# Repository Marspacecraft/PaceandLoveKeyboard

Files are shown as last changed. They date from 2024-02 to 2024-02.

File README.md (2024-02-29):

# PaceandLoveKeyboard
    受稚晖君启发，当时的铝厂的F96正好罢工，于是准备自己做一款键盘。
    改装的铝厂F96键盘
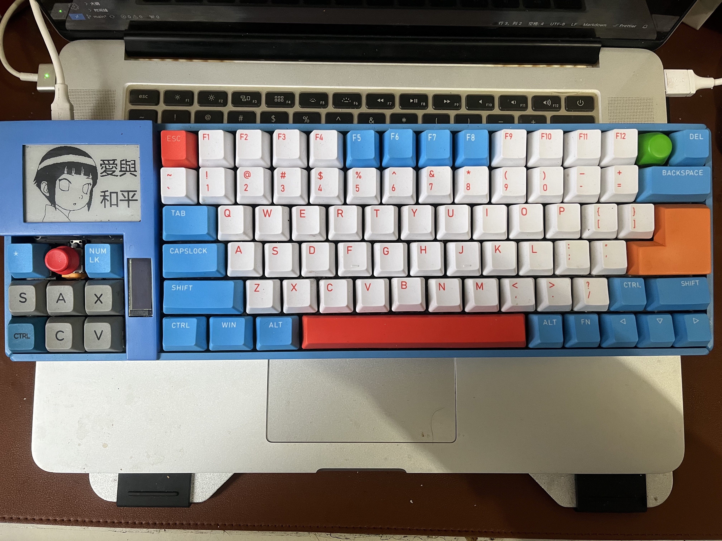
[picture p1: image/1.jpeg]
    
    当时正好缅北内战，于是起名爱与和平键盘。
## 目录
    3D-freecad做的一些3D模型
    Frameware-键盘固件
        bootloader-引导固件
        PaceandLoveKeyboard-键盘固件
            CherryUSB-usbd代理，主要实现usb的hid和mcp的串口设别
            core-键盘主要代码
                Epaper，Oled，Fonts-调试的一些显示模块驱动
                Flash-外部flash，无法作为MSC设别，暂未调试成功
                joystick-摇杆驱动
                Keyboard-键盘相关代码
                Src-系统启动等相关代码
            Fatfs-文件系统。主要用于stm32内部flash和外部flash
            OBJ-键盘固件生成目录
            SFUD-外部flash驱动
            Ymodem-串口Ymodem协议，用于串口传输文件
    Hardware-嘉立创做的硬件电路（Flash处可能存在问题，无法做将外部flash做成MSC，问题目前没有解决，flash暂时没有使用）---本人纯属自学电路制作，电路图仅供参考。
    BLE-低功耗蓝牙，采用的是nrf52832，融合了nrf的两个demo，数据可以正常发送，但问题太多，以后有时间解决。

## 键盘原理
    keybit-物理按键编号
    keycode-hid报告的键盘键值
    keycombine-按键组合。一个keycombine对应一个keybit；keycombine由4个keycode组成。一个keycombine相当于同时按下数个键。
    hid报告描述
        8bit功能按键位
        8bit填充位
        6*8bit所有按键位
        104bit普通按键位
        5bit LED显示位
        3bit填充位

        共22byte，目前LED功能没有实现。

    按键扫描采用稚晖君的方案，定时通过移位寄存器读取按键状态，将按键状态保存到sg_BitMap_New中。经过抖动延时后再次读区按键状态到sg_BitMap_Debound。通过对比将结果保存到sg_BitMap_Old中。当按键按下时通过keybit对应的keycombine找到对应的keycode进行发送。

    按键映射层通过修改keycombine映射的keycode实现不同层以及修改键值等的管理。

## 灯效
    见[rgbmode.h](https://github.com/Marspacecraft/PaceandLoveKeyboard/blob/main/Frameware/PaceAndLoveKeyboard/Core/Led/rgbmode.h)文件说明

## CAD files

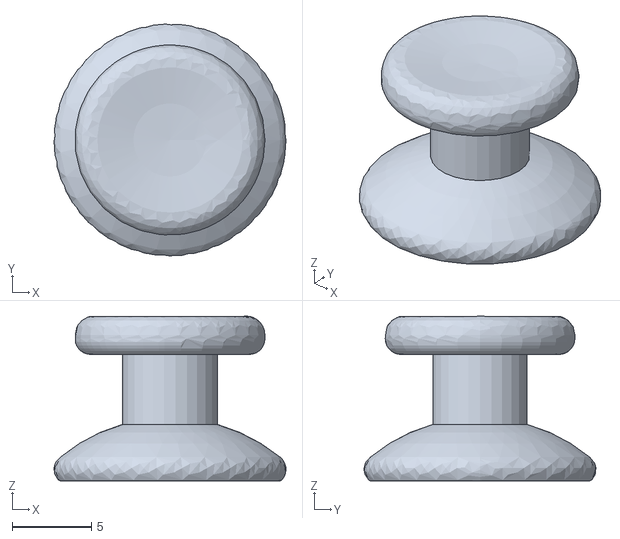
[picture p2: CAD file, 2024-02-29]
3D/Keyboard-摇杆.stl
14.7 x 14.6 x 10.4

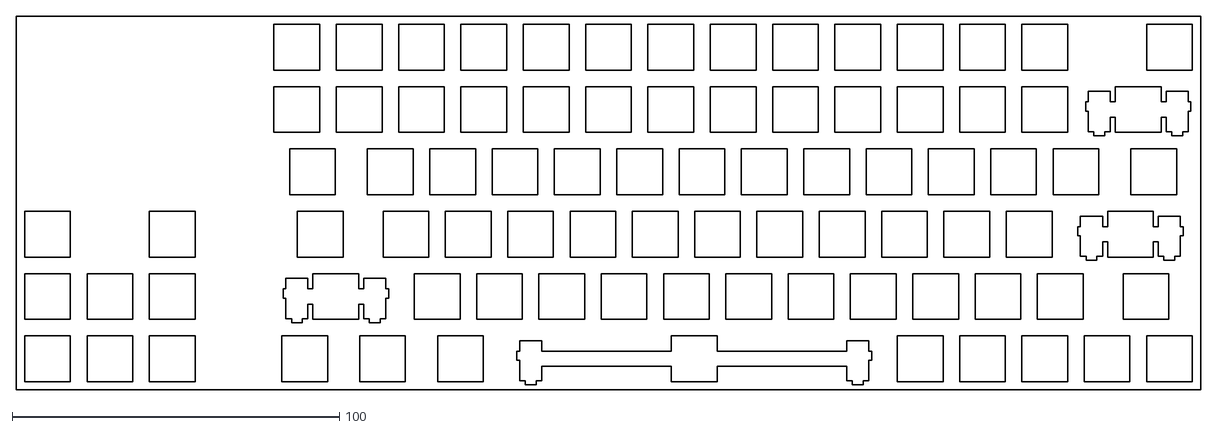
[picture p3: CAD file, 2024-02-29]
Hardware/定位板.dxf
361.9 x 114.3

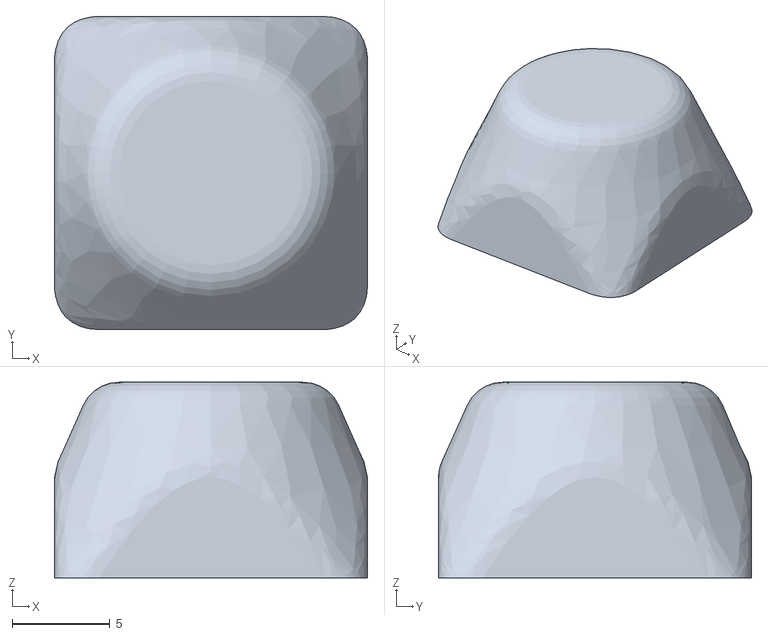
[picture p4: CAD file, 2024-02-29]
3D/Keyboard-电源键.stl
16.0 x 16.0 x 10.0

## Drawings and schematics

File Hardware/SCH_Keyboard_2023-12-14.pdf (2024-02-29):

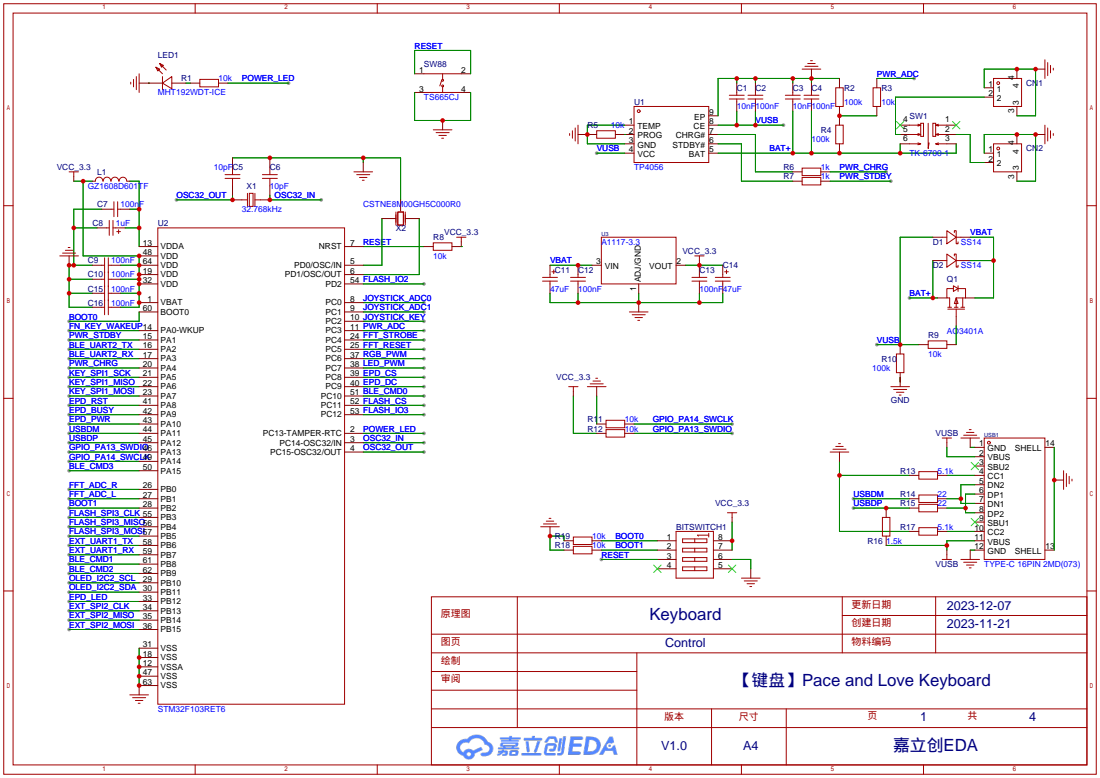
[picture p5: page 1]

【键盘】Pace and Love Keyboard

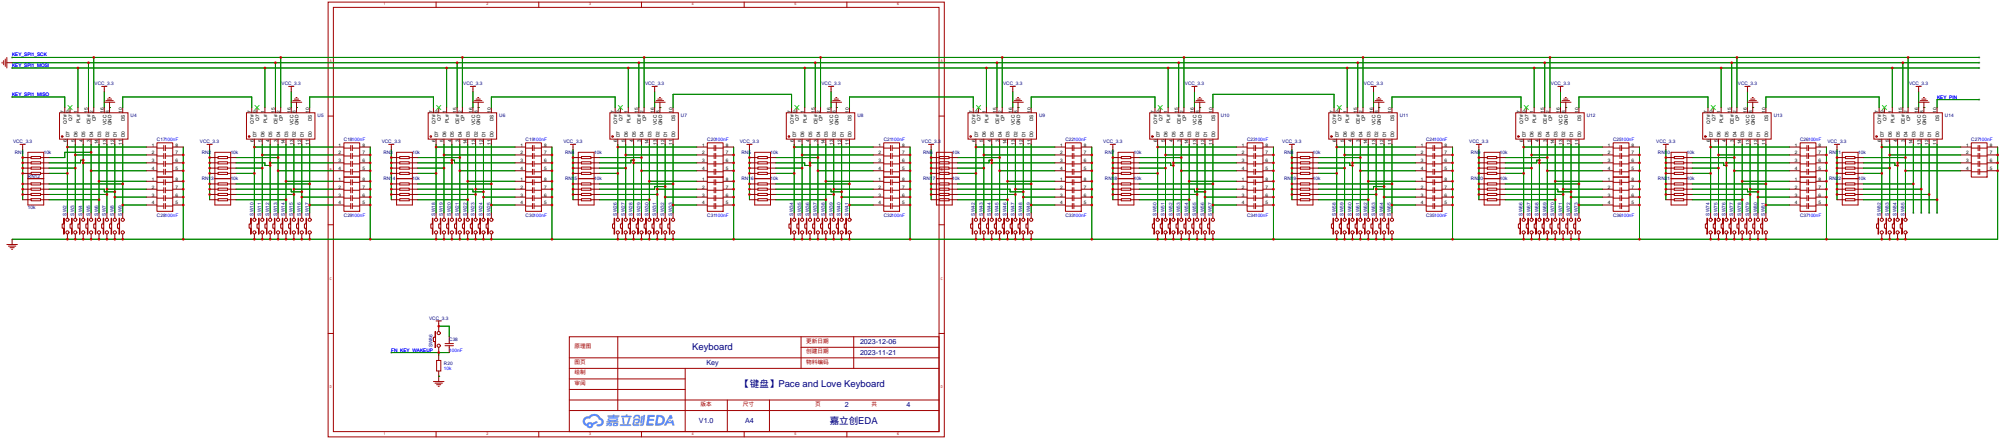
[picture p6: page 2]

KEY_SPI1_MOSI

VCC_3.3 | VCC_3.3 | VCC_3.3 | VCC_3.3 | VCC_3.3 | VCC_3.3 | VCC_3.3 | VCC_3.3 | VCC_3.3 | VCC_3.3

2023-11-21 Keyboard
Key
【键盘】Pace and Love Keyboard

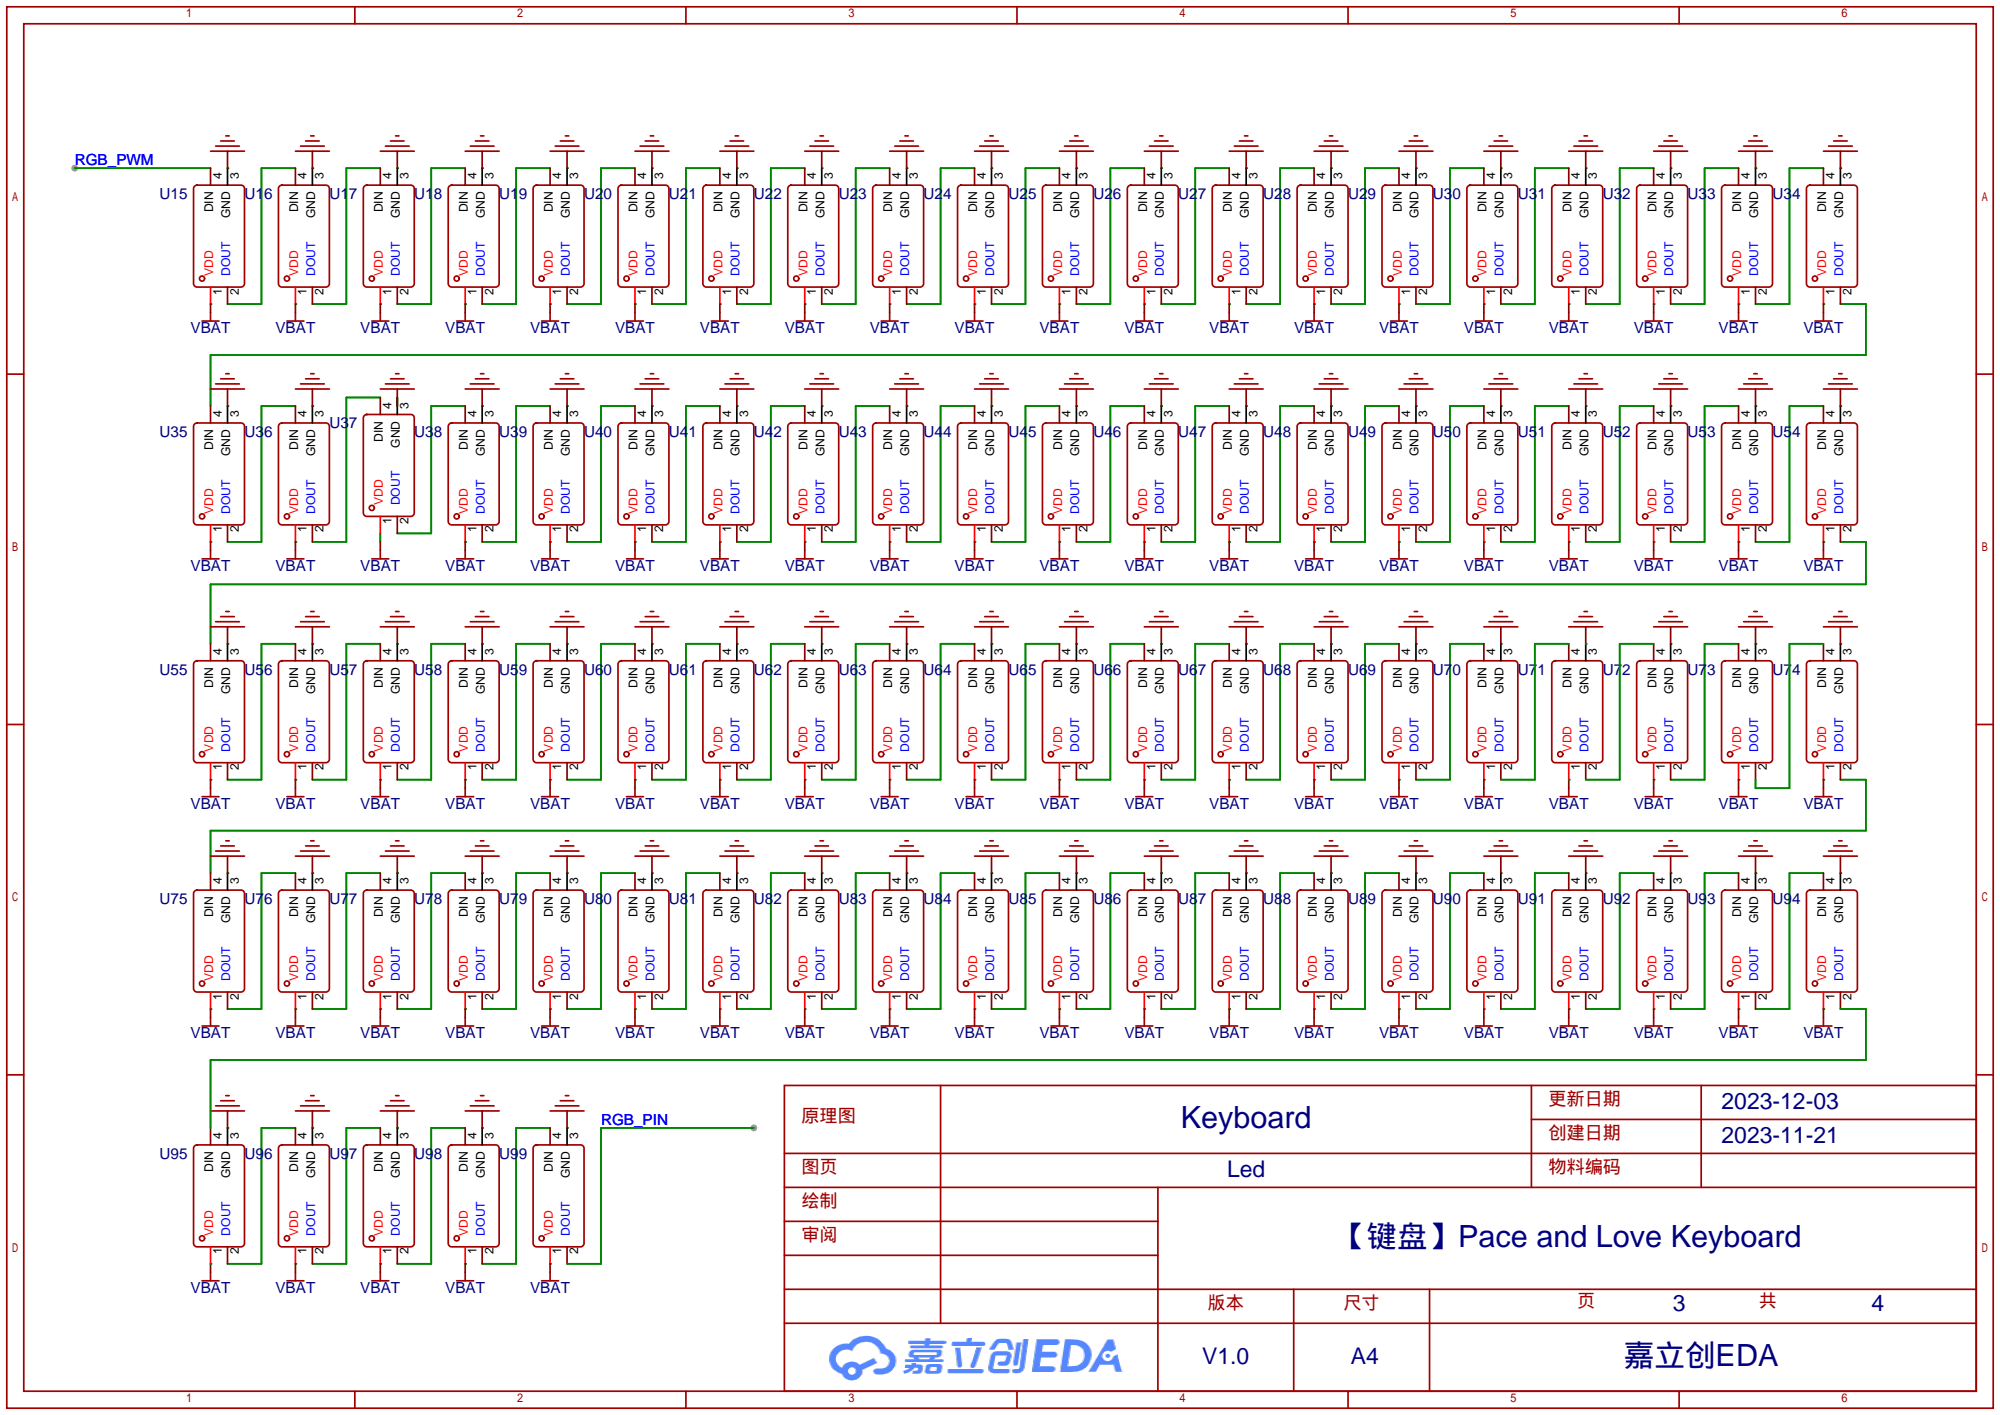
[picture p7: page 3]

2023-11-21 Keyboard
Led
【键盘】Pace and Love Keyboard

# THB001P JOYSTICK_KEY

P0.24 42 P0.23 41 P0.22 40 SWDIO 39 SWDCLK 38 P0.21 37 P0.20 36 P0.19 35 P0.18 34 P0.17 33 P0.16 32 P0.15 31 P0.14 30 P0.13 29

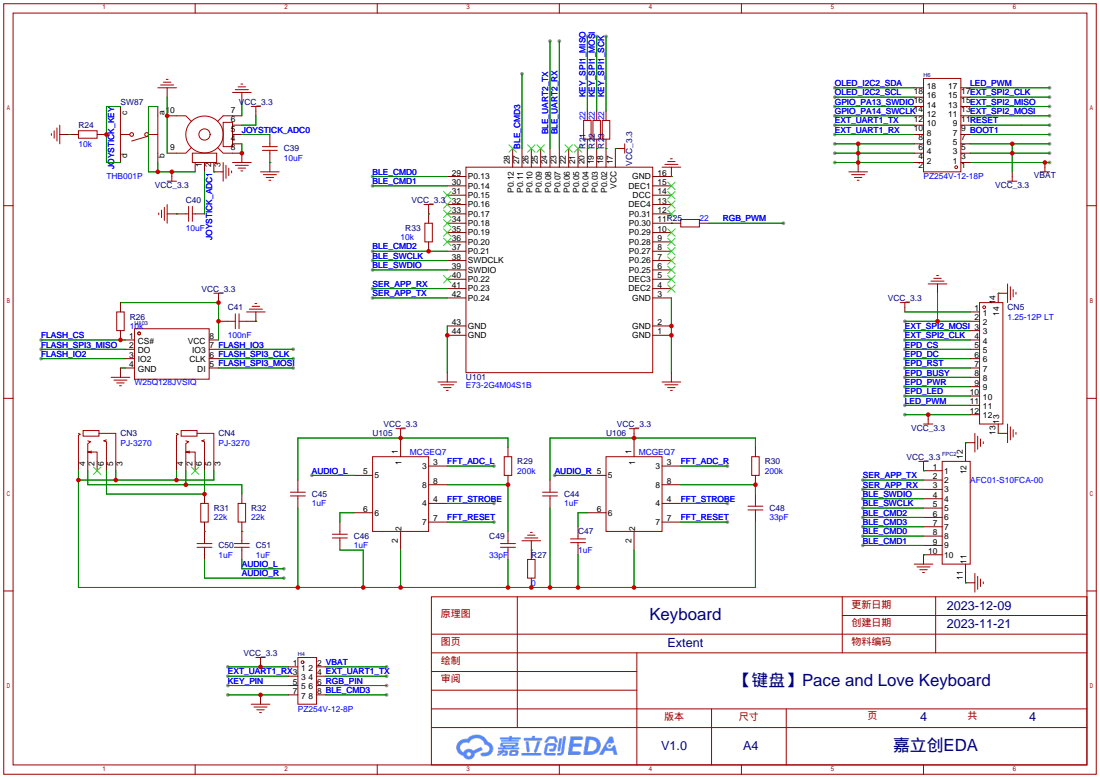
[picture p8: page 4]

2023-11-21 Keyboard
Extent
【键盘】Pace and Love Keyboard

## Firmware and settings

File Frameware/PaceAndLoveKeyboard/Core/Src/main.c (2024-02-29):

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
/* Includes ------------------------------------------------------------------*/
#include "main.h"
#include "adc.h"
#include "dma.h"
#include "i2c.h"
#include "spi.h"
#include "tim.h"
#include "usart.h"
#include "usb_device.h"
#include "gpio.h"

/* USER CODE BEGIN Includes */
#include "keyconfig.h"
#include "tracelog.h"
#include "usbd_agent.h"
#include "scheduler.h"
#include "keyboard.h"
#include "memery.h"
#include "flash.h"
#include "fatfs.h"
#include "EPD_2in7_V2.h"
#include "timertask.h"
#include "timeradc.h"
#include "joystick.h"
#include "fonts.h"
#include "st7302.h"
#include "rgb.h"
#include "ws2812b.h"
#include "oled.h"
/* USER CODE END Includes */


void SystemClock_Config(void);
/* USER CODE BEGIN 0 */


void KB_Delay_us(uint32_t us)
{
	uint32_t i = us * 18;//nop,i--,judge,jump 72/4=18

	for(;i>0;i--)
	{
		__NOP();
	}
}

bool KB_ATOMIC_CAS(volatile uint8_t *pdst,uint8_t osrc,uint8_t nsrc)
{
	bool ret = false;
	
	__disable_irq();
	
	if(*pdst == osrc)
	{
		*pdst = nsrc;
		ret = true;
	}
	__DMB();
	__enable_irq();
	return ret;
}

bool KB_ATOMIC_CAS_ADDR(volatile void **pdst,void * osrc,void * nsrc)
{
	bool ret = false;
	
	__disable_irq();
	
	if(*pdst == osrc)
	{
		*pdst = nsrc;
		ret = true;
	}
	__DMB();
	__enable_irq();
	return ret;
}

void usb_dc_low_level_init(void)
{
    /* Peripheral clock enable */
    __HAL_RCC_USB_CLK_ENABLE();
    /* USB interrupt Init */
    HAL_NVIC_SetPriority(USB_LP_CAN1_RX0_IRQn, 0, 0);
    HAL_NVIC_EnableIRQ(USB_LP_CAN1_RX0_IRQn);

}

void testcase_led_toggle(uint8_t* data)
{
	HAL_GPIO_TogglePin(POWER_LED_GPIO_Port,POWER_LED_Pin);	
}

void Throw_PowerLedTask()
{
	Start_CycleTimer(TIMER_PERIOD_500MS,testcase_led_toggle,NULL);
}

void USB_Init()
{
#ifndef TEST_USB_MSC
	if(MEM_FlagBit_IsEnabled(MEM_FLAG_USBMSC))
	{
		usbd_start_msc_mode();
		MEM_FlagBit_Reset(MEM_FLAG_USBMSC);
		MEM_FlagBit_Set(MEM_FLAG_BOOTLOADER);//enable bootloader to update firmware
	}
	else
	{
		usbd_start_hid_vcp_mode();
	}
#endif

}

void Main()
{
	RGB_CloseAll();
	RGB_Stop();
	CycleTimer_Init();
	Flash_Init();
	Fonts_Init();
	
	USB_Init();
	
	#ifdef SPI_EPAPER
		EPD_StartShow();
	#endif

	#ifdef I2C_OLED
		OLED_Init();
	#ifdef TEST_OLED
		testcase_oled();
	#endif
	#endif
	
	KEY_Init();
	Joystick_Init();

	#ifdef SPI_SHOW_LCD
	LCD_Init();
	#endif
	
	#ifdef USE_TESTCASE
		Throw_PowerLedTask();
	#endif
	
	#ifdef TEST_USB
		HAL_Delay(10000);
		testcase_usb();
	#endif

	#ifdef TEST_74HC165
		extern void testcase_74hc165(void);
 		testcase_74hc165();
	#endif

	#ifdef TEST_SCHEDULER
		testcase_scheduler();
	#endif

	#ifdef TEST_KEYTASKSCHEDULER
		testcase_keytaskscheduler();
	#endif

	#ifdef TEST_RGB
		void testcase_rgb(void);
		testcase_rgb();
	#endif

	#ifdef TEST_INTFLASH
		testcase_intflash();
	#endif
	
	#ifdef TEST_NORFLASH
		testcase_norflash();
	#endif

	#ifdef TEST_FATFS
		extern void testcase_fatfs(void);
		testcase_fatfs();
	#endif

	#ifdef TEST_USB_MSC
		testcase_usbmsc();
	#endif

	#ifdef TEST_EPAPER
		extern void testcase_ePaper(void);
		testcase_ePaper();
	#endif

	#ifdef TEST_TIMERTASK
 		testcase_timertask();
	#endif

	#ifdef TEST_ADC
		testcase_adc();
	#endif

	#ifdef TEST_JOYSTICK
		testcase_joystick();
	#else
		//ADC_Start();
		//Joystick_Start();
	#endif

	#ifdef TEST_FNKEY
		testcase_Fnkey();
	#endif

	#ifdef TEST_LCD
		extern void testcase_lcd(void);
		testcase_lcd();
	#endif

	#ifdef TEST_FONT
		extern void testcase_font(void);
 		testcase_font();
	#endif

	
	#ifdef TEST_REGMODE
		extern void testcase_testrgbmode(void);
		testcase_testrgbmode();	
	#endif

	#ifdef TEST_GT20
		extern void testcase_gt20(void);
		testcase_gt20();
	#endif

	ADC_Start();
	Joystick_Start();
	RGB_Start(RGB_Init_KeyCross);

	extern void ginisobeautiful();
	ginisobeautiful();
	
	HAL_Delay(1000);

	KEY_Scan_Start();
	
	while (1)
  	{
		do_schedule();

  	}
}

void sys_nvic_set_vector_table()
{
    SCB->VTOR = FLASH_BASE | (APP_OFFSET & (uint32_t)0xFFFFFE00);
}

/* USER CODE END 0 */

/**
  * @brief  The application entry point.
  * @retval int
  */
int main(void)
{
  /* USER CODE BEGIN 1 */
	//#ifndef USE_TESTCASE
		sys_nvic_set_vector_table();
	//#endif
	IntFlash_Init();
	init_scheduler();
  /* USER CODE END 1 */

  /* MCU Configuration--------------------------------------------------------*/

  /* Reset of all peripherals, Initializes the Flash interface and the Systick. */
  HAL_Init();

  /* Configure the system clock */
  SystemClock_Config();

  /* Initialize all configured peripherals */
  MX_GPIO_Init();
  MX_DMA_Init();
  MX_USART1_UART_Init();
  MX_SPI1_Init();
  MX_TIM6_Init();
  MX_SPI2_Init();
  MX_SPI3_Init();
  MX_USART2_UART_Init();
  MX_I2C2_Init();
  MX_TIM8_Init();
  MX_ADC1_Init();
  MX_USB_DEVICE_Init();
  /* USER CODE BEGIN 2 */
	TRACELOG_INFO("KeyBoard start!");
  TRACELOG_INFO(PALK_VERSION);
	Main();
  /* USER CODE END 2 */

  /* Infinite loop */
  /* USER CODE BEGIN WHILE */
  while (1)
  {
    /* USER CODE END WHILE */

    /* USER CODE BEGIN 3 */
  }
  /* USER CODE END 3 */
}

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


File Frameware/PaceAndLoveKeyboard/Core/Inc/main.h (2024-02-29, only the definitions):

#define POWER_LED_Pin GPIO_PIN_13
#define POWER_LED_GPIO_Port GPIOC
#define JOYSTICK_ADC0_Pin GPIO_PIN_0
#define JOYSTICK_ADC0_GPIO_Port GPIOC
#define JOYSTICK_ADC1_Pin GPIO_PIN_1
#define JOYSTICK_ADC1_GPIO_Port GPIOC
#define JOYSTICK_KEY_Pin GPIO_PIN_2
#define JOYSTICK_KEY_GPIO_Port GPIOC
#define PWR_ADC_Pin GPIO_PIN_3
#define PWR_ADC_GPIO_Port GPIOC
#define FN_KEY_WAKEUP_Pin GPIO_PIN_0
#define FN_KEY_WAKEUP_GPIO_Port GPIOA
#define FN_KEY_WAKEUP_EXTI_IRQn EXTI0_IRQn
#define PWR_STDBY_Pin GPIO_PIN_1
#define PWR_STDBY_GPIO_Port GPIOA
#define PWR_CHRG_Pin GPIO_PIN_4
#define PWR_CHRG_GPIO_Port GPIOA
#define KEY_SPI1_SCK_Pin GPIO_PIN_5
#define KEY_SPI1_SCK_GPIO_Port GPIOA
#define KEY_SPI1_MISO_Pin GPIO_PIN_6
#define KEY_SPI1_MISO_GPIO_Port GPIOA
#define KEY_PL_Pin GPIO_PIN_7
#define KEY_PL_GPIO_Port GPIOA
#define FFT_STROBE_Pin GPIO_PIN_4
#define FFT_STROBE_GPIO_Port GPIOC
#define FFT_RESET_Pin GPIO_PIN_5
#define FFT_RESET_GPIO_Port GPIOC
#define FFT_ADC_R_Pin GPIO_PIN_0
#define FFT_ADC_R_GPIO_Port GPIOB
#define FFT_ADC_L_Pin GPIO_PIN_1
#define FFT_ADC_L_GPIO_Port GPIOB
#define BOOT1_Pin GPIO_PIN_2
#define BOOT1_GPIO_Port GPIOB
#define OLED_I2C2_SCL_Pin GPIO_PIN_10
#define OLED_I2C2_SCL_GPIO_Port GPIOB
#define OLED_I2C2_SDA_Pin GPIO_PIN_11
#define OLED_I2C2_SDA_GPIO_Port GPIOB
#define EPD_LED_Pin GPIO_PIN_12
#define EPD_LED_GPIO_Port GPIOB
#define EXT_SPI2_CLK_Pin GPIO_PIN_13
#define EXT_SPI2_CLK_GPIO_Port GPIOB
#define EXT_SPI2_MISO_Pin GPIO_PIN_14
#define EXT_SPI2_MISO_GPIO_Port GPIOB
#define EXT_SPI2_MOSI_Pin GPIO_PIN_15
#define EXT_SPI2_MOSI_GPIO_Port GPIOB
#define RGB_PWM_Pin GPIO_PIN_6
#define RGB_PWM_GPIO_Port GPIOC
#define LED_PWM_Pin GPIO_PIN_7
#define LED_PWM_GPIO_Port GPIOC
#define EPD_CS_Pin GPIO_PIN_8
#define EPD_CS_GPIO_Port GPIOC
#define EPD_DC_Pin GPIO_PIN_9
#define EPD_DC_GPIO_Port GPIOC
#define EPD_RST_Pin GPIO_PIN_8
#define EPD_RST_GPIO_Port GPIOA
#define EPD_BUSY_Pin GPIO_PIN_9
#define EPD_BUSY_GPIO_Port GPIOA
#define EPD_PWR_Pin GPIO_PIN_10
#define EPD_PWR_GPIO_Port GPIOA
#define BLE_CMD3_Pin GPIO_PIN_15
#define BLE_CMD3_GPIO_Port GPIOA
#define BLE_CMD0_Pin GPIO_PIN_10
#define BLE_CMD0_GPIO_Port GPIOC
#define FLASH_CS_Pin GPIO_PIN_11
#define FLASH_CS_GPIO_Port GPIOC
#define FLASH_IO3_Pin GPIO_PIN_12
#define FLASH_IO3_GPIO_Port GPIOC
#define FLASH_IO2_Pin GPIO_PIN_2
#define FLASH_IO2_GPIO_Port GPIOD
#define FLASH_SPI3_CLK_Pin GPIO_PIN_3
#define FLASH_SPI3_CLK_GPIO_Port GPIOB
#define FLASH_SPI3_MISO_Pin GPIO_PIN_4
#define FLASH_SPI3_MISO_GPIO_Port GPIOB
#define FLASH_SPI3_MOSI_Pin GPIO_PIN_5
#define FLASH_SPI3_MOSI_GPIO_Port GPIOB
#define EXT_UART1_TX_Pin GPIO_PIN_6
#define EXT_UART1_TX_GPIO_Port GPIOB
#define EXT_UART1_RX_Pin GPIO_PIN_7
#define EXT_UART1_RX_GPIO_Port GPIOB
#define BLE_CMD1_Pin GPIO_PIN_8
#define BLE_CMD1_GPIO_Port GPIOB
#define BLE_CMD2_Pin GPIO_PIN_9
#define BLE_CMD2_GPIO_Port GPIOB

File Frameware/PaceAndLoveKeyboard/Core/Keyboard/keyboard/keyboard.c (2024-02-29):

#include "keyboard.h"
#include "main.h"
#include "usbd_agent.h"
#include <string.h>
#include "gpio.h"
#include "keylayer.h"
#include "tracelog.h"
#include "74hc165d.h"
#include "fonts.h"
#include "st7302.h"
#include "joystick.h"
#include "memery.h"
#include "oled.h"
#include "rgb.h"

#define LCD_SHOW_KEY_1U		2
#define LCD_SHOW_KEY_125U	3
#define LCD_SHOW_KEY_15U	4
#define LCD_SHOW_KEY_175U	5
#define LCD_SHOW_KEY_2U		6
#define LCD_SHOW_KEY_225U	7



#define MOUSE_BUTTON_BITMAP_LEFT	83
#define MOUSE_BUTTON_BITMAP_RIGHT	82

#define BIT_MAP_NUM ((MAX_KEY_NUM%4)?(MAX_KEY_NUM/4):((MAX_KEY_NUM/4)+1))
typedef uint32_t bitmap_t[BIT_MAP_NUM];


typedef enum
{
	FN_KEY_STATIC_FREE = 0,
	FN_KEY_STATIC_PRESSED,
	FN_KEY_STATIC_DEBOUND
}fn_static;


#define KEY_DEBOUNCE_TIME 1	//10 ms
static uint8_t sg_KeyScanCount = 3;//20 ms

static bitmap_t sg_BitMap_Old = {0};
static bitmap_t sg_BitMap_New = {0};
static bitmap_t sg_BitMap_Debound = {0};

static volatile uint8_t sg_BeSilent_flag = false;
static KeySilentModFunc sg_SilentCallBack = NULL;

static hid_keyboard sg_KeyCode_buffer = {0};
;
static fn_static sg_fn_stat = FN_KEY_STATIC_FREE;

void KEY_ShowKeyBit(uint8_t x,uint8_t y,keybit_t bit,uint8_t u);


/************************************************************************************************

	Keybit function

************************************************************************************************/

void For_Each_KeyBit(ForEachBitFunc_f func,bitmap_t bitmap)
{
	uint32_t* map_32 = bitmap;
	keybit_t bit;
	uint8_t i;//32

	for(i=0;i<BIT_MAP_NUM;i++)
	{
		if(map_32[i])
		{
			uint16_t * map_16 = (uint16_t *)&map_32[i];
			uint8_t j;//16
			for(j=0;j<2;j++)
			{
				if(map_16[j])
				{
					uint8_t * map_8 = (uint8_t*)&map_16[j];
					uint8_t k;//8
					for(k=0;k<2;k++)
					{
						if(map_8[k])
						{
							uint8_t l;
							for(l=0;l<8;l++)
							{
								if(map_8[k] & (0x80 >> l))
								{
									bit = i*32 + j*16 + k*8 + l;
									func(bit);
								}
							}
						}
					}
				}
			}
		}
	}

}

void For_Each_KeyBit_Press(ForEachBitFunc_f func)
{
	For_Each_KeyBit(func,sg_BitMap_Old);
}

uint8_t Get_ChangedKeyBitMap(bitmap_t map,bitmap_t bitmap)
{
	uint8_t i;
	uint8_t ret = false;

	for(i=0;i<BIT_MAP_NUM;i++)
	{
		map[i] = sg_BitMap_Old[i] ^ bitmap[i];
		if(map[i])
		{
			ret = true;
		}
	}

	return ret;
}

uint8_t For_Each_KeyBit_Changed(ForEachBitFunc_f func,bitmap_t bitmap,bitmap_t chmap)
{
	
	if(Get_ChangedKeyBitMap(chmap,bitmap))
	{
		For_Each_KeyBit(func,chmap);
		return true;
	}
	return false;
}

bool KeyBit_IsFreeing(keybit_t bitmap)
{
	uint8_t pos = bitmap/8;
	uint8_t bitpos = bitmap%8;
	uint8_t* pOled = (uint8_t*)(sg_BitMap_Old);
	uint8_t* pDebound = (uint8_t*)(sg_BitMap_Debound);

	if((pOled[pos]&(0x80>>bitpos))&&((~pDebound[pos])&(0x80>>bitpos)))
		return true;
	return false;
}

bool KeyBit_IsPressing(keybit_t bitmap)
{
	uint8_t pos = bitmap/8;
	uint8_t bitpos = bitmap%8;
	uint8_t* pOled = (uint8_t*)(sg_BitMap_Old);
	uint8_t* pDebound = (uint8_t*)(sg_BitMap_Debound);

	if((pDebound[pos]&(0x80>>bitpos))&&((~pOled[pos])&(0x80>>bitpos)))
		return true;
	return false;
}

bool KeyBit_IsPressed(keybit_t bitmap)
{
	uint8_t pos = bitmap/8;
	uint8_t bitpos = bitmap%8;
	uint8_t* pOled = (uint8_t*)(sg_BitMap_Old);

	if(pOled[pos]&(0x80>>bitpos))
		return true;
	return false;
}

bool MouseButton_Left_IsPressed(void)
{
	return KeyBit_IsPressed(MOUSE_BUTTON_BITMAP_LEFT);
}

bool MouseButton_Right_IsPressed(void)
{
	return KeyBit_IsPressed(MOUSE_BUTTON_BITMAP_RIGHT);
}


/********************************************************************************************

	other

********************************************************************************************/
 uint8_t* KEY_Get_KeyBitMap_Buffer(void);
 uint8_t* KEY_Get_KeyBitMap_Debounce_Buffer(void);
 
 //if need to debounce and return true,or send key code to host and return false.
 uint8_t KEY_Updata_KeyBitMap_Buffer(void);
 //send key code to host 
 void KEY_Updata_KeyBitMap_Debounce_Buffer(void);


 void KeyCode_Change(keycode_t code,uint8_t pressed)
{
	if(pressed)
	{
		//TRACELOG_DEBUG_PRINTF("SetCodec [%x]",code);
		USBD_Keyboard_SetCodec(&sg_KeyCode_buffer,code);
		//USBD_Print_Keyboard_Report(&sg_KeyCode_buffer);
	}
	else
	{
		//TRACELOG_DEBUG_PRINTF("ResetCodec [%x]",code);
		USBD_Keyboard_ResetCodec(&sg_KeyCode_buffer,code);
		//USBD_Print_Keyboard_Report(&sg_KeyCode_buffer);
	}
}


void KeyBit_Change(keybit_t bit)
{
	uint8_t pressed = KeyBit_IsPressing(bit);

	if(false == sg_BeSilent_flag)
	{
		For_Each_Bit_KeyCode(bit, KeyCode_Change,pressed);
	}
}


void Updata_BitMapOld_2_HIDBuffer(keybit_t bit)
{
	For_Each_Bit_KeyCode(bit, KeyCode_Change,true);
}

void Updata_KeyBitMapBuffer_Old()
{
	memcpy(sg_BitMap_Old,sg_BitMap_Debound,sizeof(bitmap_t));
}

void ResetChanged_DuringDebounce()
{
	for(uint8_t i=0;i<BIT_MAP_NUM;i++)
	{
		uint32_t difbit = ~(sg_BitMap_Debound[i]^sg_BitMap_New[i]);
		sg_BitMap_Debound[i] &= difbit;
	}
}
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

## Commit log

2024-02-29 首次提交
    首次提交
    [Keyboard-摇杆.stl, Keyboard-电源键.stl, 定位板.dxf]
2024-02-29 删除DS文件
    删除DS文件
2024-02-29 添加说明
    添加说明
2024-02-29 增加说明
    增加说明

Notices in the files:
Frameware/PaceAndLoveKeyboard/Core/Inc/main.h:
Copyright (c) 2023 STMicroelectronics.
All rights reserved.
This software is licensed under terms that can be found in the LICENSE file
